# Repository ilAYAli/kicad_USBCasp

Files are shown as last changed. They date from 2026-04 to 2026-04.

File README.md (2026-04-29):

# USBCasp

Compact USB-C AVR programmer based on the classic USBasp design and an `ATmega8`.

### PCB
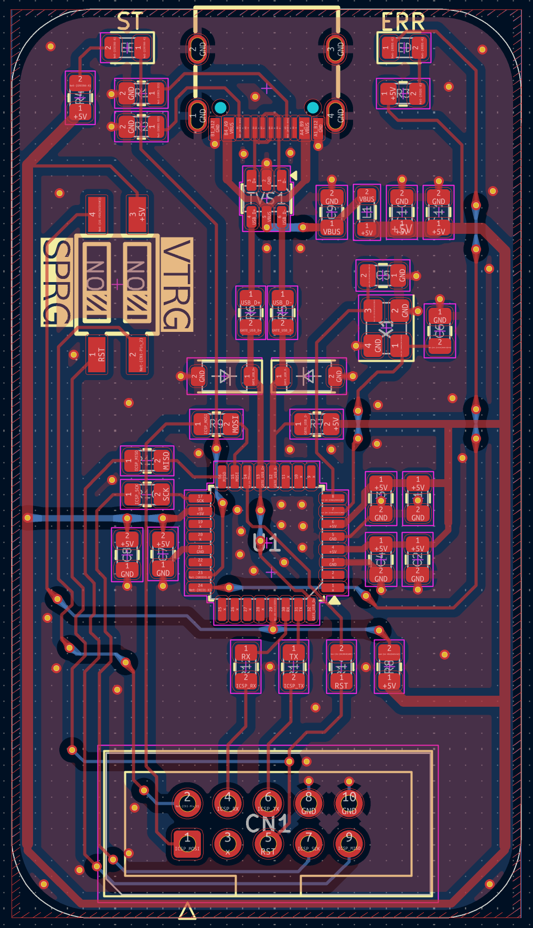
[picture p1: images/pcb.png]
PCB layout


### Finished product
PCB layout

## Hardware

This project is a USBasp-compatible AVR ISP programmer with:

- `ATmega8-16AU`
- `12 MHz` external crystal
- USB-C connector with USB 2.0 data pair
- 2x5 ICSP header for programming target AVRs

The USBasp firmware in this repo is configured for:

- `D- = PB0`
- `D+ = PB1`
- `D+` also tied to `PD2 / INT0`
- `12 MHz` clock

### Firmare

```sh
git clone https://github.com/Ser9ei/usbasp.git
```

## Programming One USBasp From Another

If you already have one working USBasp, you can use it to program another `ATmega8` USBasp target over the ICSP header.
If the board does not enumerate as USBasp yet, replace `-c usbasp` with your external programmer, for example `-c avrisp2`.

Set `SPRG` on the target board to `ON`, connect the two boards through the 2x5 ISP header, then run:

### Program using a pre-programmed USBasp

```sh
avrdude -c usbasp -p m8 -B 10 -U hfuse:w:0xc9:m -U lfuse:w:0xef:m
avrdude -c usbasp -p m8 -B 10 -e -U ./firmware/usbasp/firmware/usbasp_atmega8_2026-04-12.hex:i
```

### Program using an avrisp2

```sh
avrdude -c avrisp2 -p m8 -B 10 -U hfuse:w:0xc9:m -U lfuse:w:0xef:m
avrdude -c avrisp2 -p m8 -B 10 -e -U ./firmware/usbasp/firmware/usbasp_atmega8_2026-04-12.hex:i
```

### Verify the firmware (connect the newly programmed USBCasp)

```sh
avrdude -c usbasp -p m8 -n -v
```

### Then verify real ISP communication against a known-good target AVR:

```sh
avrdude -c usbasp -p m8 -B 32 -v
```

Or for a different target, for example `ATtiny84`:

```sh
avrdude -c usbasp -p t84 -B 32 -v
```

## Repo Layout

- [USBCasp.kicad_sch](USBCasp.kicad_sch) and [USBCasp.kicad_pcb](USBCasp.kicad_pcb): hardware design
- [firmware/usbasp/firmware](https://github.com/Ser9ei/usbasp.git): USBasp firmware source and build artifacts
- [firmware/FLASH_AND_TEST.md](firmware/FLASH_AND_TEST.md): extra flashing and bring-up notes

## Original implementation

https://www.fischl.de/usbasp/

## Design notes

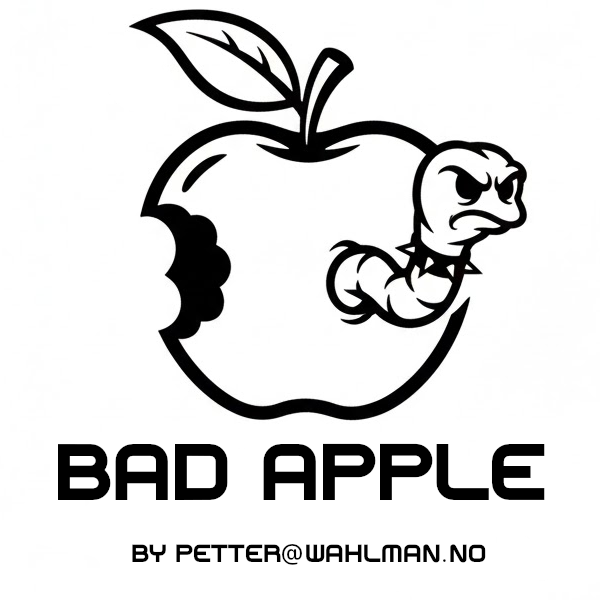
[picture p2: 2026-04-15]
images/BadApple.png

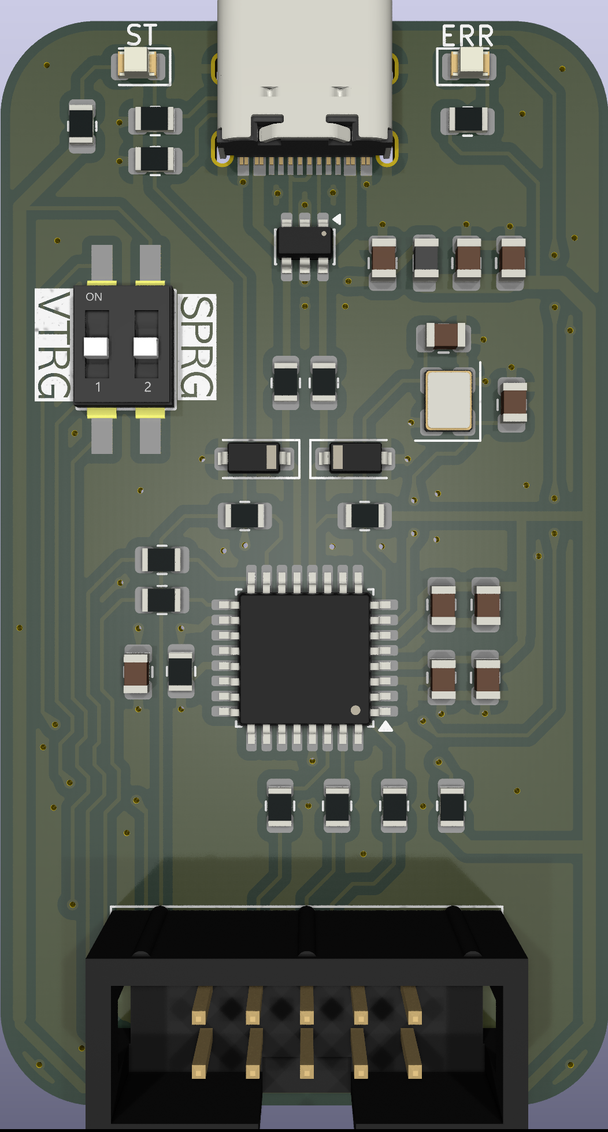
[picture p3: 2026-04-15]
images/renderer.png

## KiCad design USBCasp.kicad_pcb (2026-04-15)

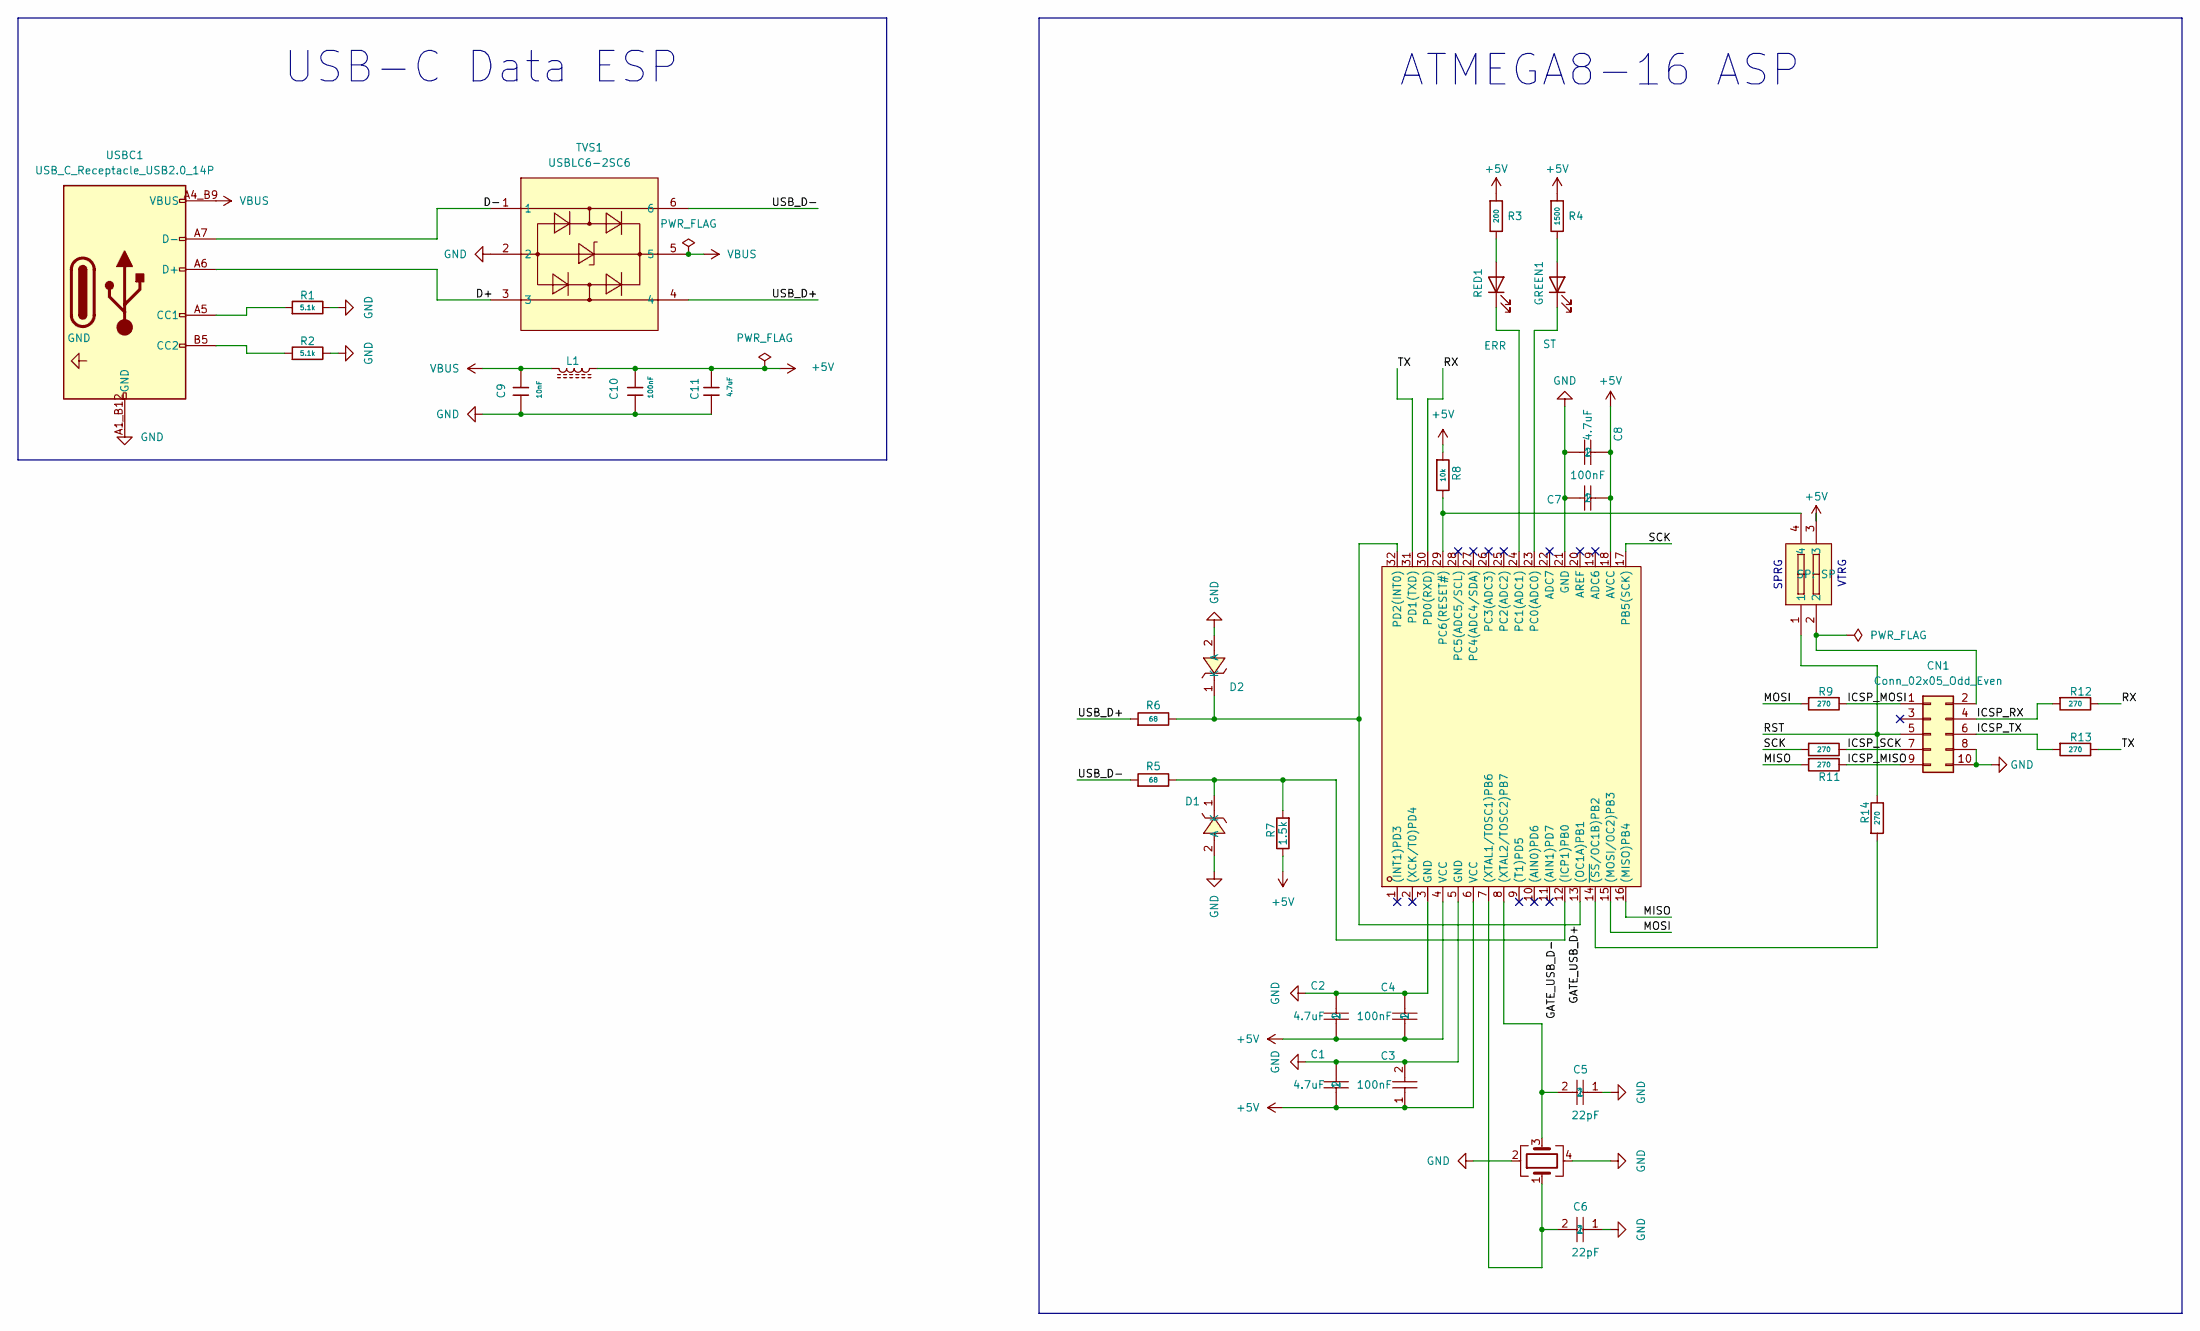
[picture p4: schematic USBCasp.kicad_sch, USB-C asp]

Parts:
C1, C2, C8: 4.7uF; C_0805_2012Metric; Part CL21A475KBQNNNE; LCSC Part C98192
C3, C4: 100nF; C_0805_2012Metric; Part CC0805KRX7R9BB104; LCSC Part C49678
C5, C6: 22pF; C_0805_2012Metric; Part CL21C220JBANNNC; LCSC Part C1804
C7: 100nF; R_0805_2012Metric; Part CC0805KRX7R9BB104; LCSC Part C49678
C9: 10nF; C_0805_2012Metric; Part CC0805KRX7R9BB103; LCSC C83170
C10: 100nF; C_0805_2012Metric; LCSC C49678
C11: 4.7uF; C_0805_2012Metric; Part GRM21BZ71H475KE15L; LCSC C437557
CN1: Conn_02x05_Odd_Even; IDC-Header_2x05_P2.54mm_Vertical
D1, D2: BZT52C3V6_C19077397; D_SOD-123; LCSC Part C19077397
GREEN1: ST; LED_0805_2012Metric; Mfr. Part NCD0805G1; LCSC Part C8426
L1: 600; L_0805_2012Metric; Mrf part MPZ2012S601AT000; LCSC Part C21519
R1, R2: 5.1k; R_0805_2012Metric; Part 0805W8F5101T5E; LCSC C27834
R3: 200; R_0805_2012Metric; Part FRC0805F2000TS; LCSC C2907239
R4: 1500; R_0805_2012Metric; Mfr. Part RC0805FR-071K5L; LCSC C114555
R5, R6: 68; R_0805_2012Metric; Part 0805W8F680JT5E; LCSC C17802
R7: 1.5k; R_0805_2012Metric; Part 0805W8F3600T5E; LCSC Part C114555
R8: 10k; R_0805_2012Metric; Part RC0805FR-0710KL; LCSC C84376
R9, R10, R11, R12, R13, R14: 270; R_0805_2012Metric; Part RC0805FR-07270RL; LCSC Part C137558
RED1: ERR; LED_0805_2012Metric; Mfr. Part YLED0805R; LCSC Part C19171391
TVS1: USBLC6-2SC6; SOT-23-6; LCSC Part C7519
U1: ATMEGA8-16AU; TQFP-32_7x7mm_P0.8mm; LCSC Part C1337807
U2: SMXS-02K-TP; SW-SMD_SMXS-02K-TP; LCSC Part 2
USBC1: USB_C_Receptacle_USB2.0_14P; USB-C_Receptacle
X1: 12Mhz; Crystal_SMD_3225-4Pin_3.2x2.5mm; Part X322512MSB4SI; LCSC C9002

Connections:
+5V: C1.1, C2.1, C3.1, C4.1, C7.2, C8.2, C10.1, C11.1, L1.1, R3.1, R4.1, R7.2, R8.1, U1.4 (VCC), U1.6 (VCC), U1.18 (AVCC), U2.3
/D+: TVS1.3, USBC1.A6 (D+), USBC1.B6 (D+)
/D-: TVS1.1, USBC1.A7 (D-), USBC1.B7 (D-)
/GATE_USB_D+: D2.1 (K), R6.2, U1.13 ((OC1A)PB1), U1.32 (PD2(INT0))
/GATE_USB_D-: D1.1 (K), R5.2, R7.1, U1.12 ((ICP1)PB0)
/ICSP_MISO: CN1.9, R11.1
/ICSP_MOSI: CN1.1, R9.1
/ICSP_RX: CN1.4, R12.2
/ICSP_SCK: CN1.7, R10.1
/ICSP_TX: CN1.6, R13.2
/MISO: R11.2, U1.16 ((MISO)PB4)
/MOSI: R9.2, U1.15 ((MOSI/OC2)PB3)
/RST: CN1.5, R14.1, U2.1
/RX: R12.1, U1.30 (PD0(RXD))
/SCK: R10.2, U1.17 (PB5(SCK))
/TX: R13.1, U1.31 (PD1(TXD))
/USB_D+: R6.1, TVS1.4
/USB_D-: R5.1, TVS1.6
GND: C1.2, C2.2, C3.2, C4.2, C5.1, C6.1, C7.1, C8.1, C9.2, C10.2, C11.2, CN1.8, CN1.10, D1.2 (A), D2.2 (A), R1.2, R2.2, TVS1.2, U1.3 (GND), U1.5 (GND), U1.21 (GND), USBC1.1, USBC1.2, USBC1.3, USBC1.4, USBC1.A1_B12 (GND), USBC1.B1_A12 (GND), X1.2, X1.4
unnamed: CN1.2, U2.2
unnamed: GREEN1.2 (A), R4.2
unnamed: GREEN1.1 (K), U1.23 (PC0(ADC0))
unnamed: R3.2, RED1.2 (A)
unnamed: RED1.1 (K), U1.24 (PC1(ADC1))
unnamed: C6.2, U1.7 ((XTAL1/TOSC1)PB6), X1.1
unnamed: C5.2, U1.8 ((XTAL2/TOSC2)PB7), X1.3
unnamed: R8.2, U1.29 (PC6(RESET#)), U2.4
unnamed: R14.2, U1.14 (~(SS/OC1B)PB2)
unnamed: R1.1, USBC1.A5 (CC1)
unnamed: R2.1, USBC1.B5 (CC2)
VBUS: C9.1, L1.2, TVS1.5, USBC1.A4_B9 (VBUS), USBC1.B4_A9 (VBUS)

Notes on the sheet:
SPRG
VTRG
ATMEGA8-16 ASP
USB-C Data ESP

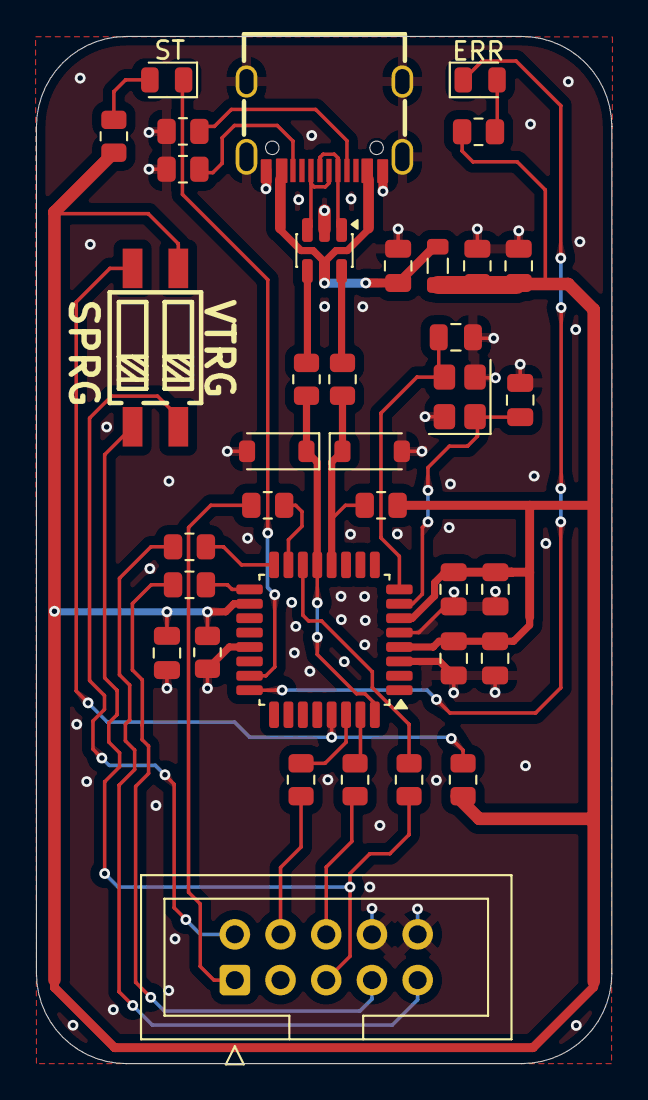
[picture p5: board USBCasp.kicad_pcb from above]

Board: 2 copper layers, 32.0 x 57.1 mm, 36 parts (0 on the bottom side), 31 nets.
